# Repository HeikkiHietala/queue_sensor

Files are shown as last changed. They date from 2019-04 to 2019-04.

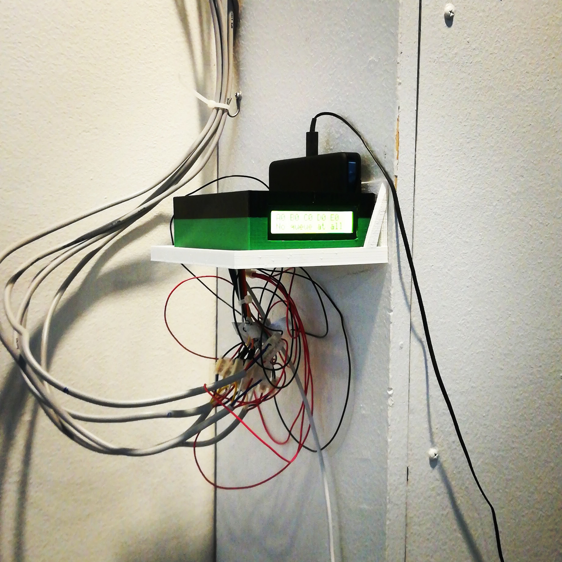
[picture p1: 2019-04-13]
IMG_20190319_130045_178.jpg

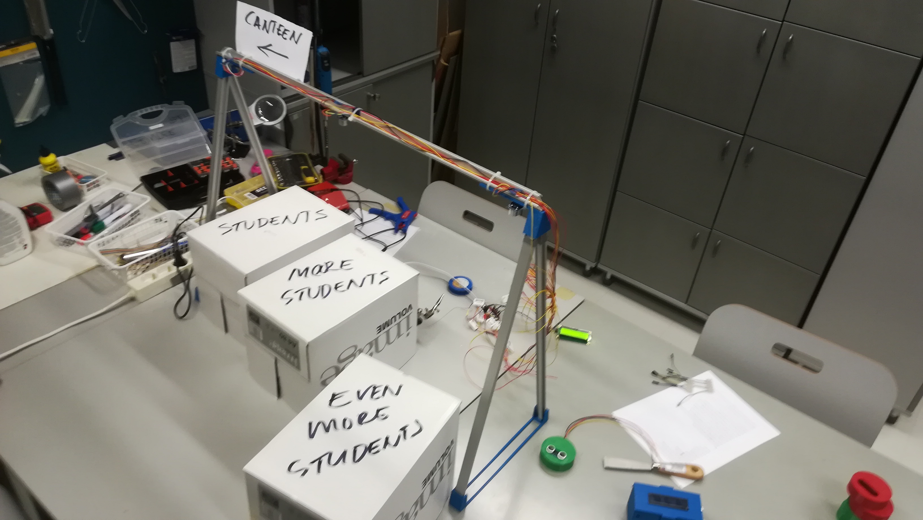
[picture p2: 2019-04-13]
IMG_20190201_104045.jpg

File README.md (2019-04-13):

# Five sensor queue monitor with LCD
This device allows you to monitor five ultrasound sensors and find out the length of the queue. MicroPython, ESP32, HC-SR04, LCD display, and Internet connection.

LCD library from dhylands.

FILES:
canteen.php is the file on the server to which the device sends its measurements once a minute.
canteen-5-final.py is the file that runs on the ESP32 and monitors the five HC-SR04 sensors and measures the distance between the sensor and the ground. There is a variable, BaseAverage, which must be set to the height of the area where the system is installed. Also, you need to give your SSID and password in this file.

Other files are libraries needed for the ESP32 to run the HC-SR04 and the LCD, as well as the MicroPython requests and JSON.

STL fines are for 3D printing the parts necessary for housing the unit and fastening the sensors to the ceiling. 

Note that the lid does not contain sides, as they were made from clear plastic, and not printed.

See http://www.sabulo.com/sb/3d-printing-2/low-cost-low-impact-queue-monitoring-system/ for how this thing works. 

Also, many images on Instagram at @isohoo3d

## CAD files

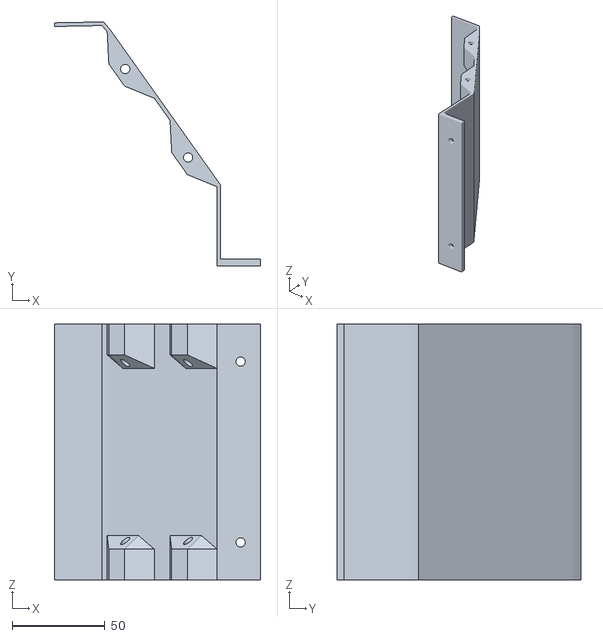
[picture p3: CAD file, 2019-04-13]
device rack lid.stl
111.4 x 132.0 x 138.3

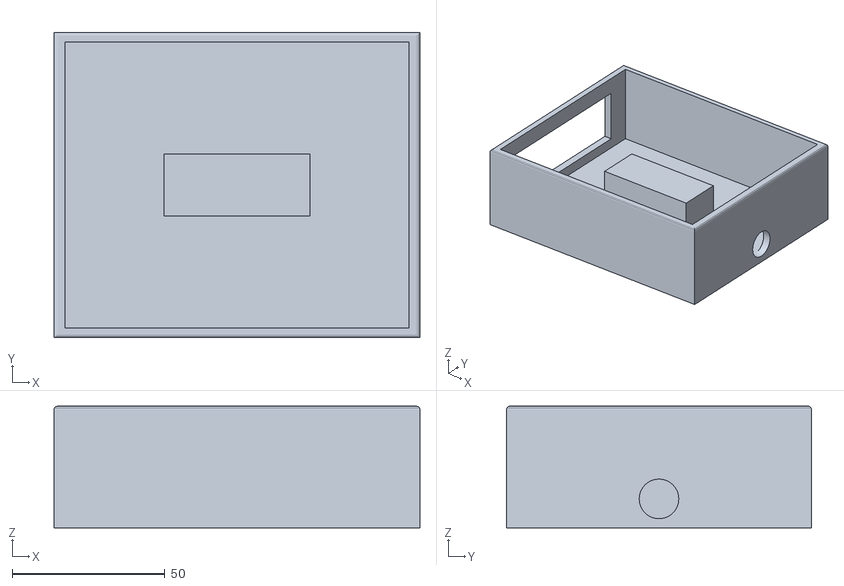
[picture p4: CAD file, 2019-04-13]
device box.stl
120.0 x 100.0 x 40.0

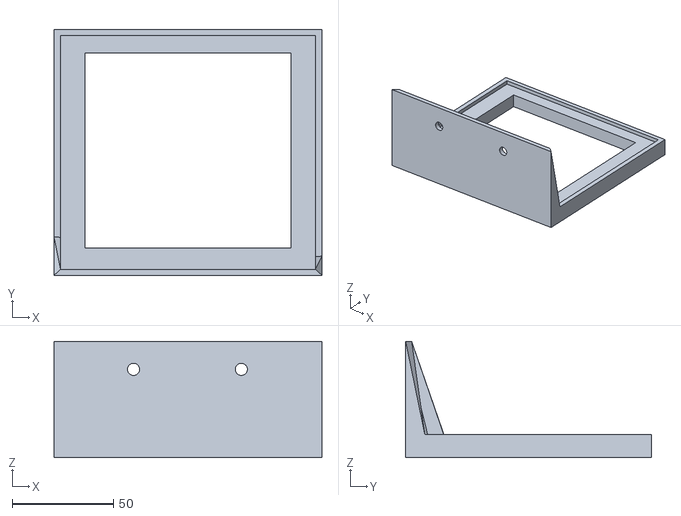
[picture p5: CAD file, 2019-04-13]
device rack.stl
132.5 x 121.4 x 57.5

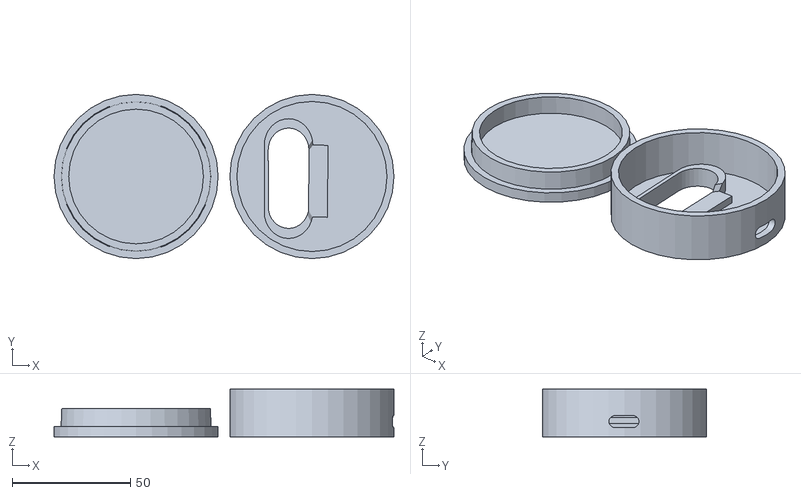
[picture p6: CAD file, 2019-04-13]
sensor box.stl
144.0 x 69.5 x 20.2

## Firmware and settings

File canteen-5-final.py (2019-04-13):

try:
    from time import sleep_ms, ticks_ms
    from machine import I2C, Pin, DAC, PWM
    import esp8266_i2c_lcd 
    from hcsr04 import HCSR04
    import network
    import socket
    import urequests
    import machine
    import json
    
    SSID = "your_SSID" 
    PASSWORD = "your_password"  
    port=100
    wlan=None
    s=None
    
    mySensorArray1 = [0,0,0,0,0,0,0,0,0,0]
    mySensorArray2 = [0,0,0,0,0,0,0,0,0,0]
    mySensorArray3 = [0,0,0,0,0,0,0,0,0,0]
    mySensorArray4 = [0,0,0,0,0,0,0,0,0,0]
    mySensorArray5 = [0,0,0,0,0,0,0,0,0,0]

    hitCount1 = 0
    hitCount2 = 0
    hitCount3 = 0
    hitCount4 = 0
    hitCount5 = 0
    
    mySensor1 = HCSR04(trigger_pin = 12, echo_pin = 4)
    mySensor2 = HCSR04(trigger_pin = 14, echo_pin = 16)
    mySensor3 = HCSR04(trigger_pin = 27, echo_pin = 17)
    mySensor4 = HCSR04(trigger_pin = 26, echo_pin = 5)
    mySensor5 = HCSR04(trigger_pin = 25, echo_pin = 18)
    
    mySensorBaseAvg = 270 ##REMEMBER TO SET TO ACTUAL VALUE!
    
    for x in range(9):
        mySensorArray1[x] = mySensorBaseAvg
    for x in range(9):
        mySensorArray2[x] = mySensorBaseAvg 
    for x in range(9):
        mySensorArray3[x] = mySensorBaseAvg
    for x in range(9):
        mySensorArray4[x] = mySensorBaseAvg
    for x in range(9):
        mySensorArray5[x] = mySensorBaseAvg
      
    i2c = I2C(scl=Pin(21), sda=Pin(22), freq=400000)
    lcd = esp8266_i2c_lcd.I2cLcd(i2c, 0x27, 4, 20)
    
    lcd.move_to(0,0)
    lcd.putstr("Base avg:" + str(mySensorBaseAvg))
    sleep_ms(2000)
    
    def cycleValues(pickSensor):
        for x in range(9):
            pickSensor[x] = pickSensor[x+1]
        
        
    def connectWifi(ssid,passwd): #function to connect to the Web
        global wlan #declare a WLAN object
        lcd.move_to(0, 0) #move LCD cursor to top left corner
        lcd.putstr("Connect to WLAN") #write the string to the LCD
        wlan=network.WLAN(network.STA_IF)                     #create a wlan object
        wlan.active(True)                                     #Activate the network interface
        wlan.disconnect()                                     #Disconnect the last connected WiFi
        wlan.connect(ssid,passwd)                             #connect wifi
        while(wlan.ifconfig()[0]=='0.0.0.0'): #wait for connection
          sleep_ms(1)
        sleep_ms(1000) #hold on for 1 second
        lcd.move_to(0, 0) #move cursor to top left corner
        lcd.putstr("Connected      ") #write the string to LCD, note the blanks to erase the previous message
        url = "your_PHP_file_for_handling_input"
        headers = {'content-type': 'application/json'}
        data = {'message': 'Boot sequence complete with canteen-5-final.py'}
        jsonObj = json.dumps(data)
        resp = urequests.post(url, data=jsonObj, headers=headers)
        sleep_ms(1000)  #hold on for 1 second
        lcd.clear() #clear the LCD screen
        return True
        
    
    def main():
      connectWifi(SSID,PASSWORD)
      minuteCounter = 0
      while True:
        hitCount1 = 0
        hitCount2 = 0
        hitCount3 = 0
        hitCount4 = 0
        hitCount5 = 0
        
        cycleValues(mySensorArray1)
        mySensorArray1[9] = mySensor1.distance_cm()
        cycleValues(mySensorArray2)
        mySensorArray2[9] = mySensor2.distance_cm()
        cycleValues(mySensorArray3)
        mySensorArray3[9] = mySensor3.distance_cm()
        cycleValues(mySensorArray4)
        mySensorArray4[9] = mySensor4.distance_cm()
        cycleValues(mySensorArray5)
        mySensorArray5[9] = mySensor5.distance_cm()

        for x in range(9):
          if mySensorArray1[x] < 2 * mySensorBaseAvg / 3:
            hitCount1 += 1
        for x in range(9):
          if mySensorArray2[x] < 2 * mySensorBaseAvg / 3:
            hitCount2 += 1
        for x in range(9):
          if mySensorArray3[x] < 2 * mySensorBaseAvg / 3:
            hitCount3 += 1
        for x in range(9):
          if mySensorArray4[x] < 2 * mySensorBaseAvg / 3:
            hitCount4 += 1
        for x in range(9):
          if mySensorArray5[x] < 2 * mySensorBaseAvg / 3:
            hitCount5 += 1

        lcd.move_to(0,0)
        lcd.putstr("A" + str(hitCount1))
        lcd.move_to(3,0)
        lcd.putstr("B" + str(hitCount2))
        lcd.move_to(6,0)
        lcd.putstr("C" + str(hitCount3))
        lcd.move_to(9,0)
        lcd.putstr("D" + str(hitCount4))
        lcd.move_to(12,0)
        lcd.putstr("E" + str(hitCount5))
        lcd.move_to(0,1)
        
        if (hitCount1 > 6 and hitCount2 > 6 and hitCount3 > 6 and hitCount4 > 6 and hitCount5 > 6 ):
            myQueueStatus = "A massive queue   "
        elif (hitCount1 > 6 and hitCount2 > 6 and hitCount3 > 6 and hitCount4 > 6 ):
            myQueueStatus = "A long queue        "
        elif (hitCount1 > 6 and hitCount2 > 6 and hitCount3 > 6):
            myQueueStatus = "A medium queue      "
        elif (hitCount1 > 6 and hitCount2 > 6):
            myQueueStatus = "A short queue       "
        elif (hitCount1 > 6):
            myQueueStatus = "A minimal queue     "
        else:
            myQueueStatus = "No queue at all     "
        lcd.putstr(myQueueStatus)    
        sleep_ms(1000)

        print("A:" + str(int(mySensor1.distance_cm())) + " " + "B:"+ str(int(mySensor2.distance_cm())) + " " + "C:"+ str(int(mySensor3.distance_cm()))+ " D:"+ str(int(mySensor4.distance_cm()))+ " " + "E:"+ str(int(mySensor5.distance_cm())))
        print("A: " + str(hitCount1) + " " + "B: "+ str(hitCount2) + " " + "C: "+ str(hitCount3) + " " + "D: "+ str(hitCount4) + " " + "E: "+ str(hitCount5))
        myQueueSensorData = "A:" + str(hitCount1) + " " + "B:"+ str(hitCount2) + " " + "C:"+ str(hitCount3) + " " + "D:"+ str(hitCount4) + " " + "E:"+ str(hitCount5)
        myQueueSensorDist = "A:" + str(int(mySensor1.distance_cm())) + " " + "B:"+ str(int(mySensor2.distance_cm())) + " " + "C:"+ str(int(mySensor3.distance_cm()))+ " D:"+ str(int(mySensor4.distance_cm()))+ " " + "E:"+ str(int(mySensor5.distance_cm()))
        minuteCounter += 1
        if (minuteCounter % 60 == 0):
          try:
            url = "your_PHP_file_for_handling_input"
            headers = {'content-type': 'application/json'}
            data = {'message': myQueueStatus + " " + myQueueSensorData + " " +myQueueSensorDist }
            jsonObj = json.dumps(data)
            resp = urequests.post(url, data=jsonObj, headers=headers)
            minuteCounter=0
          except Exception as e:
            connectWifi(SSID,PASSWORD)
            f = open('buglog.txt','a')
            f.write("WLAN issue"+"\n")
            f.close()
        #lcd.clear()
        
    main()
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

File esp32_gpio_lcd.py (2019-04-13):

"""Implements a HD44780 character LCD connected via ESP32 GPIO pins."""

from lcd_api import LcdApi
from machine import Pin
from utime import sleep_ms, sleep_us


class GpioLcd(LcdApi):
    """Implements a HD44780 character LCD connected via ESP32 GPIO pins."""

    def __init__(self, rs_pin, enable_pin, d0_pin=None, d1_pin=None,
                 d2_pin=None, d3_pin=None, d4_pin=None, d5_pin=None,
                 d6_pin=None, d7_pin=None, rw_pin=None, backlight_pin=None,
                 num_lines=2, num_columns=16):
        """Constructs the GpioLcd object. All of the arguments must be machine.Pin
        objects which describe which pin the given line from the LCD is
        connected to.

        When used in 4-bit mode, only D4, D5, D6, and D7 are physically
        connected to the LCD panel. This function allows you call it like
        GpioLcd(rs, enable, D4, D5, D6, D7) and it will interpret that as
        if you had actually called:
        GpioLcd(rs, enable, d4=D4, d5=D5, d6=D6, d7=D7)

        The enable 8-bit mode, you need pass d0 through d7.

        The rw pin isn't used by this library, but if you specify it, then
        it will be set low.
        """
        self.rs_pin = rs_pin
        self.enable_pin = enable_pin
        self.rw_pin = rw_pin
        self.backlight_pin = backlight_pin
        self._4bit = True
        if d4_pin and d5_pin and d6_pin and d7_pin:
            self.d0_pin = d0_pin
            self.d1_pin = d1_pin
            self.d2_pin = d2_pin
            self.d3_pin = d3_pin
            self.d4_pin = d4_pin
            self.d5_pin = d5_pin
            self.d6_pin = d6_pin
            self.d7_pin = d7_pin
            if self.d0_pin and self.d1_pin and self.d2_pin and self.d3_pin:
                self._4bit = False
        else:
            # This is really 4-bit mode, and the 4 data pins were just
            # passed as the first 4 arguments, so we switch things around.
            self.d0_pin = None
            self.d1_pin = None
            self.d2_pin = None
            self.d3_pin = None
            self.d4_pin = d0_pin
            self.d5_pin = d1_pin
            self.d6_pin = d2_pin
            self.d7_pin = d3_pin
        self.rs_pin.init(Pin.OUT)
        self.rs_pin.value(0)
        if self.rw_pin:
            self.rw_pin.init(Pin.OUT)
            self.rw_pin.value(0)
        self.enable_pin.init(Pin.OUT)
        self.enable_pin.value(0)
        self.d4_pin.init(Pin.OUT)
        self.d5_pin.init(Pin.OUT)
        self.d6_pin.init(Pin.OUT)
        self.d7_pin.init(Pin.OUT)
        self.d4_pin.value(0)
        self.d5_pin.value(0)
        self.d6_pin.value(0)
        self.d7_pin.value(0)
        if not self._4bit:
            self.d0_pin.init(Pin.OUT)
            self.d1_pin.init(Pin.OUT)
            self.d2_pin.init(Pin.OUT)
            self.d3_pin.init(Pin.OUT)
            self.d0_pin.value(0)
            self.d1_pin.value(0)
            self.d2_pin.value(0)
            self.d3_pin.value(0)
        if self.backlight_pin is not None:
            self.backlight_pin.init(Pin.OUT)
            self.backlight_pin.value(0)

        # See about splitting this into begin

        sleep_ms(20)   # Allow LCD time to powerup
        # Send reset 3 times
        self.hal_write_init_nibble(self.LCD_FUNCTION_RESET)
        sleep_ms(5)    # need to delay at least 4.1 msec
        self.hal_write_init_nibble(self.LCD_FUNCTION_RESET)
        sleep_ms(1)
        self.hal_write_init_nibble(self.LCD_FUNCTION_RESET)
        sleep_ms(1)
        cmd = self.LCD_FUNCTION
        if not self._4bit:
            cmd |= self.LCD_FUNCTION_8BIT
        self.hal_write_init_nibble(cmd)
        sleep_ms(1)
        LcdApi.__init__(self, num_lines, num_columns)
        if num_lines > 1:
            cmd |= self.LCD_FUNCTION_2LINES
        self.hal_write_command(cmd)

    def hal_pulse_enable(self):
        """Pulse the enable line high, and then low again."""
        self.enable_pin.value(0)
        sleep_us(1)
        self.enable_pin.value(1)
        sleep_us(1)       # Enable pulse needs to be > 450 nsec
        self.enable_pin.value(0)
        sleep_us(100)     # Commands need > 37us to settle

    def hal_write_init_nibble(self, nibble):
        """Writes an initialization nibble to the LCD.

        This particular function is only used during initialization.
        """
        self.hal_write_4bits(nibble >> 4)

    def hal_backlight_on(self):
        """Allows the hal layer to turn the backlight on."""
        if self.backlight_pin:
            self.backlight_pin.value(1)

    def hal_backlight_off(self):
        """Allows the hal layer to turn the backlight off."""
        if self.backlight_pin:
            self.backlight_pin.value(0)

    def hal_write_command(self, cmd):
        """Writes a command to the LCD.

        Data is latched on the falling edge of E.
        """
        self.rs_pin.value(0)
        self.hal_write_8bits(cmd)
        if cmd <= 3:
            # The home and clear commands require a worst
            # case delay of 4.1 msec
            sleep_ms(5)

    def hal_write_data(self, data):
        """Write data to the LCD."""
        self.rs_pin.value(1)
        self.hal_write_8bits(data)

    def hal_write_8bits(self, value):
        """Writes 8 bits of data to the LCD."""
        if self.rw_pin:
            self.rw_pin.value(0)
        if self._4bit:
            self.hal_write_4bits(value >> 4)
            self.hal_write_4bits(value)
        else:
            self.d3_pin.value(value & 0x08)
            self.d2_pin.value(value & 0x04)
            self.d1_pin.value(value & 0x02)
            self.d0_pin.value(value & 0x01)
            self.hal_write_4bits(value >> 4)

    def hal_write_4bits(self, nibble):
        """Writes 4 bits of data to the LCD."""
        self.d7_pin.value(nibble & 0x08)
        self.d6_pin.value(nibble & 0x04)
        self.d5_pin.value(nibble & 0x02)
        self.d4_pin.value(nibble & 0x01)
        self.hal_pulse_enable()
